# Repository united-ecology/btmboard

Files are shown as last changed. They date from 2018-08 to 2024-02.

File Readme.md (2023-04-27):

# BtM Board 1.2

This project is an Arduino based datalogger for monitoring moss conductance as well as environmental humidity and temperature. Up to eight moss and/or lichen samples can be logged in parallel using a single BtMboard. If you are interested in using it, do not hesitate to contact :)

This repository is associated with the following publication: Leo, M., Lareo, A., Garcia-Saura, C., Hortal, J., Medina, N. G. BtM, a Low-cost Open-source Datalogger to Estimate the Water Content of Nonvascular Cryptogams. *J. Vis. Exp.* (145), e58700, [doi:10.3791/58700](https://doi.org/10.3791/58700) (2019).

A video with further instructions on how to build and use the datalogger can be found in the paper link: [BtM, a Low-cost Open-source Datalogger to Estimate the Water Content of Nonvascular Cryptogams](https://www.jove.com/video/58700/btm-low-cost-open-source-datalogger-to-estimate-water-content). Notice that version 1.0 was used in the recording, and it might slightly differ from the current version.

Do not switch off the datalogger while measuring (LED light on). It can be switched off safely during the sleeping period (LED light off). 

## Sofware

This software folder contains the source code needed to use the BtM datalogger. Make sure you choose the appropriate board (Pro Mini 328 3.3V) in the Arduino IDE.

*Libraries* contains the libraries needed for the datalogger. Copy them to your local Arduino IDE installation in the `/libraries` folder. 

*Clock* contains a project to set up the date / hour of the BtM datalogger. It will set it according to your local system clock.

*Datalog* contains the main project used to log the data. The sampling frequency can be controlled here by modifying `interval` (sleeping period in seconds). Make sure you select the appropriate sensor (SHT7x / SHT85). See [this documentation](datalog-config.md) on how to do it.

## Hardware
The hardware folder contains the KiCAD project files for the BtM PCB Board. See the **List of Components** section for details about the hardware needed to assembly the board.

### Assembly schematic

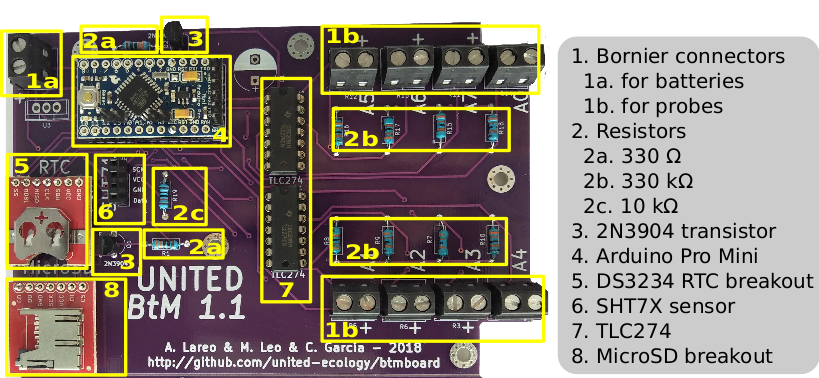
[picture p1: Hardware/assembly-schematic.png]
Assembly Schematic


### Obtaining measures

 As shown in the image, a voltage divider between each sample (Moss) and a resistor reference (Ref) with a known value (330KΩ in our case) is used to calculate the conductance measure. Probes are applied to each moss/lichen sample. Reference resistor value must be selected through calibration and based on previous measures of the cryptogams. It provides a resolution of one order of magnitude around the reference value (in our case, 100 – 1000 KΩ).

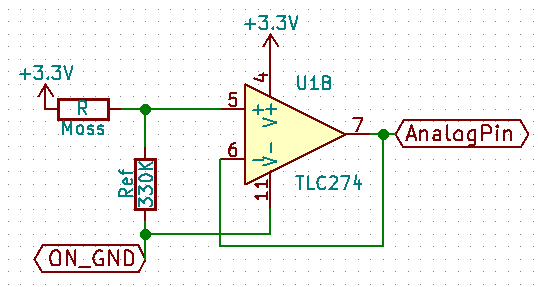
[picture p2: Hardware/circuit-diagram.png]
Circuit Diagram


### List of Components
* BtMboard circuit (PCB)
* Arduino Pro Mini 328 3.3 V
* FTDI Basic Breakout
* MiniUSB to USB cable adapter
* TLC274 operational amplifier
* 2.54 mm breakout pin strip
* Resistors (8 x 330 Kohm, 2 x 330 Ohm, 1 x 10 KOhm)
* 2N3904 Transistor
* 9 x Bornier connectors, 2x1 5.08 mm
* Batteries and battery holder with switch
* Sensirion SHT7x / SHT85
* DS3234 RTC Breakout (clock)
* CR1225 3V Coin-cell battery
* MicroSD Transflash breakout

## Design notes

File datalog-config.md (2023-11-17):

# Datalog

## Logging interval

Modify this portion of the code for modifying the logging interval (default to 10 seconds):
```
const uint8_t interval = 10;  // set logging interval in SECONDS, eg: set 300 seconds for an interval of 5 mins
```

For example, to log every 10 minutes:
```
const uint8_t interval = 600;  // set logging interval in SECONDS, eg: set 300 seconds for an interval of 5 mins
```

## Sensor selection

Modify this portion of the code for selecting the appropriate sensor (default to SHT85):
```
// SELECT the appropriate sensor
// #define SHT71SENSOR
#define SHT85SENSOR
```

If you are using **SHT7x**, change it this way:
```
// SELECT the appropriate sensor
#define SHT71SENSOR
// #define SHT85SENSOR
```
## Problem with time shifts

Depending in the system configuration, you may experience problems with time shifts when programming the Arduino board. To fix this:

1. Find the following line in the code:
```
const int timeshift = 0; // Change this variable if you are experiencing time shift problems (in seconds, i.e. -3600 to shift one hour) 
```

2. Modify it to increase/decrease the shift, in order to adjust the clock time to the correct time.

## Serial debug RTC

Uncomment this (remove //) to turn on clock debug prompts through the serial port:
```
#define DEBUG_RTC
```

## Serial debug sensors

Uncomment this (remove //) to turn on sensor debug prompts through serial port:
```
#define DEBUG_SENSORS
```

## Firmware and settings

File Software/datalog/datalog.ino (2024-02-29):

//****************************************************************
// Data logging software from Leo, Lareo et al. 2018
// v1.2 <angel.lareo@gma>
//****************************************************************

// SELECT the appropriate sensor
// #define SHT71SENSOR
#define SHT85SENSOR

#include <EEPROM.h>
#include <RtcDS3234.h>
#ifdef SHT71SENSOR
  #include <Sensirion.h>
#else // SHT85SENSOR
  #include <SoftwareWire.h>
  #include <SHT85.h>
#endif
#include <SdFat.h>
#include <sdios.h>
#include <SPI.h>
#include <PowerSaver.h>

// #define DEBUG_RTC
// #define DEBUG_SENSORS
#define DEBUG_SD 0
#define PRINT_DELAY 7 // Increase this if strange characters appear in serial prints

// Constants
#define POWA 4    // pin 4 supplies power to microSD card breakout and SHT15 sensor
#define PINON 7
#define NREADS 4
#define ANALOGMAX 8
#define RtcSquareWavePin 8 // Arduino Pro Mini
#define maxSDLines2Serial 5
#define line_buffer_size 300
#define SHT85_ADDRESS 0x44

// Launch Variables   ******************************
const uint16_t interval = 300;  // set logging interval in SECONDS, eg: set 300 seconds for an interval of 5 mins
char filename_prefix[] = "";
char filename_ext[] = ".csv";
char filename[20];    // Set filename Format: "12345678.123". Cannot be more than 8 characters in length, contain spaces or begin with a number
const int timeshift = 0; // Change this variable if you are experiencing time shift problems (in seconds, i.e. -3600 to shift one hour) 

// Global objects and variables   ******************************
const int SDcsPin = 9;        // pin 9 is CS pin for MicroSD breakout
const uint8_t DS3234_CS_PIN = 10; // RTC SS pin
const uint8_t SHT_clockPin = 3;   // pin used for SCK on SHT85 breakout
const uint8_t SHT_dataPin = 5;    // pin used for DATA on SHT85 breakout
const float VCC = 3.3;            // Con Vcc=3.3V lo máximo que da el TL274 es 2.73V
const float Voffset = 0.00;
int RValue = 330;
int fileLastHour=-1;
int nSDLines2Serial=0;

RtcDateTime time;
PowerSaver chip;  	// declare object for PowerSaver class
RtcDS3234<SPIClass> RTC(SPI, DS3234_CS_PIN);

#ifdef SHT71SENSOR
  Sensirion sensor(SHT_dataPin, SHT_clockPin);  // declare object for SHT71 class
#else // SHT85SENSOR
  SoftwareWire myWire(SHT_dataPin, SHT_clockPin);
  SHT85 sensor;  // declare object for SHT85 class
#endif
SdFat sd; 		    // declare object for SdFat class

// ISR ****************************************************************
ISR(PCINT0_vect)  // Interrupt Vector Routine to be executed when pin 8 receives an interrupt.
{
  asm("nop");
}

// setup ****************************************************************
void setup()
{
  Serial.begin(115200); // open serial at 19200 bps
  while (!Serial);
  
  pinMode(POWA, OUTPUT);      // set output pins
  pinMode(PINON, OUTPUT);     // set output pins
  digitalWrite(POWA, LOW);    // turn off SD card
  digitalWrite(PINON, LOW);   // turn off sensors

  // set the interupt pin to input mode
  pinMode(RtcSquareWavePin, INPUT_PULLUP); // external pullup maybe required still
  
  SPI.begin();

  setupRTC();

  time = RTC.GetDateTime();

  #ifdef SHT85SENSOR
    myWire.begin();
    sensor.begin(SHT85_ADDRESS,&myWire);
    myWire.setClock(100000UL);
  #endif
  
  delay(1);

  chip.sleepInterruptSetup();
}

// loop ****************************************************************
void loop()
{ 
  #ifdef DEBUG_RTC
    Serial.print(time.Hour());
    Serial.print(":");
    Serial.print(time.Minute());
    Serial.print(":");
    Serial.print(time.Second());
  #endif

  time = time+interval;
  #ifdef DEBUG_RTC
    Serial.print(" - Next alarm at ");
    SerialDebugRTC();
    delay(PRINT_DELAY);
  #endif
  setNextAlarm(time);      //set next alarm before sleeping
  
  chip.turnOffADC();        // turn off ADC to save power
  chip.turnOffSPI();        // turn off SPI bus to save power
  //chip.turnOffWDT();      // turn off WatchDog Timer to save power (does not work for Pro Mini - only works for Uno)
  chip.turnOffBOD();        // turn off Brown-out detection to save power
  pinMode(SCK,OUTPUT);      // turnOffSPI lo había dejado en alto y como entrada
  digitalWrite(SCK, LOW);   // Para garantizar que el LED verde de SCK se apaga

  chip.goodNight();    // put processor in extreme power down mode - GOODNIGHT!
  // this function saves previous states of analog pins and sets them to LOW INPUTS
  // average current draw on Mini Pro should now be around 0.195 mA (with both onboard LEDs taken out)
  // Processor will only wake up with an interrupt generated from the RTC, which occurs every logging interval

  // code will resume from here once the processor wakes up =============== //
  chip.turnOnADC();    // enable ADC after processor wakes up
  chip.turnOnSPI();   // turn on SPI bus once the processor wakes up
  delay(1);    // important delay to ensure SPI bus is properly activated

  time = RTC.GetDateTime();
  uint8_t hour = time.Hour();

  #ifdef DEBUG_RTC
    Serial.print("Awake at ");
    SerialDebugRTC();
  #endif
  
  RTC.LatchAlarmsTriggeredFlags();    // clear alarm flag
  
  pinMode(POWA, OUTPUT);
  pinMode(PINON, OUTPUT);

  float temperature;
  float humidity; 
  float RData[8];

  // Medida analógica de impedancias
  digitalWrite(PINON, HIGH);    // turn on sensors
  delay(10);
  getDataFromSensors(&temperature,&humidity,RData);
  #ifdef DEBUG_SENSORS
    SerialDebugSensors(&temperature,&humidity,RData);
  #endif
  digitalWrite(PINON, LOW);     // turn off microSD card to save power

  // Grabación de medidas en memoria SD
  digitalWrite(POWA, HIGH);    // turn on SD card
  delay(1);    // give some delay to ensure RTC and SD are initialized properly
  
  pinMode(SDcsPin, OUTPUT);
  if (!sd.begin(SdSpiConfig(SDcsPin))){   // very important - reinitialize SD card on the SPI bus
    if (DEBUG_SD) Serial.println("SD ERROR");
    sd.initErrorPrint();
    return;
  }


  if (hour==0 && fileLastHour==23){
    fileLastHour=-1;
  }
  if (hour>fileLastHour){
    delay(1);
    fileLastHour = time.Hour();
    doFilename(time.Month(),time.Day(),fileLastHour);
    initFile();
    delay(1);
  }
  
  printDataEntry2File(&temperature,&humidity,RData);
  lastSDLine2Serial();
  // if (nSDLines2Serial<maxSDLines2Serial){
  //   nSDLines2Serial++;
  //   Serial.println("");
  //   Serial.print("[");
  //   Serial.print(nSDLines2Serial);
  //   Serial.print("] ");
  //   lastSDLine2Serial();
  // }
  
  sd.end();
  delay(1);
//  SPCR = 0;  // reset SPI control register
  digitalWrite(POWA, LOW);    // turn off microSD card to save power
  digitalWrite(PINON, LOW);   // turn off microSD card to save power
}






// ------------------------------------------------
//  FUNCTIONS
// ------------------------------------------------

void setupRTC(){
  RTC.Begin();

  RtcDateTime compiled = RtcDateTime(__DATE__, __TIME__);

  compiled += timeshift;
  if (timeshift != 0) {
     RTC.SetDateTime(compiled);
  }
  
  if (!RTC.IsDateTimeValid()) {
      // Serial.println("RTC lost confidence in the DateTime!");
      RTC.SetDateTime(compiled);
  }

  if (!RTC.GetIsRunning()) {
      // Serial.println("RTC was not actively running, starting now");
      RTC.SetIsRunning(true);
  }
  
  RtcDateTime now = RTC.GetDateTime();
  if (now < compiled) {
      // Serial.println("RTC is older than compile time!  (Updating DateTime)");
      RTC.SetDateTime(compiled);
  }
  
  RTC.Enable32kHzPin(false);
  RTC.SetSquareWavePin(DS3234SquareWavePin_ModeAlarmBoth); 
}

void initFile(){
  ofstream file(filename,ios_base::app);
  if (!file.is_open()) {
    if (DEBUG_SD){
      Serial.print("SDFile ERR: ");
      Serial.println(filename);
    }
    sd.errorHalt("open");
  }
  file << "Date/Time,Temp(C),RH(%),A0_Imp(ohm),A1_Imp(ohm),A2_Imp(ohm),A3_Imp(ohm),A4_Imp(ohm),A5_Imp(ohm),A6_Imp(ohm),A7_Imp(ohm)\n";    // Print header to file
  file.close();    // close file - very important
}

void getDataFromSensors(float* temperature, float* humidity, float* RData){
  for (int a = A0; a < A0 + ANALOGMAX; a++)
    for (int i = 0; i < NREADS; i++)
      analogRead(a);  // first few readings from ADC may not be accurate, so they're cleared out here
  delay(1);

  // Read moss data
  for (int a = 0; a < ANALOGMAX; a++){
    float adcData = averageADC(A0+a);
    RData[a] = mossImpedance(adcData, RValue); //Reference resistor value
  }

  #ifdef SHT71SENSOR
    float dew;
    sensor.measure(temperature,humidity,&dew);
  #else // SHT85SENSOR
    // Read sensor data
    sensor.read(); 
    *temperature = sensor.getTemperature();
    *humidity = sensor.getHumidity();
  #endif
}

void setNextAlarm(RtcDateTime next){
  DS3234AlarmOne alarm1(
            next.Day(),
            next.Hour(),
            next.Minute(), 
            next.Second(),
            DS3234AlarmOneControl_HoursMinutesSecondsMatch);
  RTC.SetAlarmOne(alarm1);
  RTC.LatchAlarmsTriggeredFlags();
}

void lastSDLine2Serial(){
  Serial.print("buff: ");
  char buffer[line_buffer_size];

  fstream file(filename);
  
  bool keepLooping = true;
  file.seekg(-3,ios_base::end);

  while(keepLooping) {
    char ch;
    file.get(ch);                            // Get current byte's data
    
    if((int)file.tellg() <= 1) {             // If the data was at or before the 0th byte
        file.seekg(0);                       // The first line is the last line
        keepLooping = false;                // So stop there
    }
    else if(ch == '\n') {                   // If the data was a newline
        keepLooping = false;                // Stop at the current position.
    }
    else {                                  // If the data was neither a newline nor at the 0 byte
        file.seekg(-2,ios_base::cur);        // Move to the front of that data, then to the front of the data before it
    }
  }
           
  file.getline(buffer, line_buffer_size, '\n');                      // Read the current line
  file.close();
  
  Serial.println(buffer);     // Display it
  delay(PRINT_DELAY);

}

void printDataEntry2File(float* temperature, float* humidity, float* RData){
  ofstream file(filename,ios_base::app);

  file << time.Year();
  file << "-";
  int d = time.Month();
  if (d < 10) file << '0';
  file << d;
  file << "-";
  d = time.Day();
  if (d < 10) file << '0';
  file << d;
  file << " ";
  d = time.Hour();
  if (d < 10) file << '0';
  file << d;
  file << ":";
  d = time.Minute();
  if (d < 10) file << '0';
  file << d;
  file << ":";
  d = time.Second();
  if (d < 10) file << '0';
  file << d;
  file << ",";
  if (*temperature < 10) file << '0';
  file << *temperature;
  file << ",";
  if (*humidity < 10) file << '0';
  file << *humidity;
  for (int a = 0; a < ANALOGMAX; a++){
    file << ",";
    file << RData[a];
  }
  file << "\n";
  file.close();
  
  //Needed who knows why ¯\_(ツ)_/¯
  file.open(filename,ios_base::app);
  file.close();
}

// Averaging ADC values to counter noise in readings  *********************************************
float averageADC(int pin){
  float sum = 0.0;
  for (int i = 0; i < NREADS; i++){
    sum = sum + analogRead(pin);
  }
  float average = sum / NREADS;
  return average;
}

// Get mossImp ****************************************************************
float mossImpedance(float adc, int R){
  float Zmoss=99999.0;
  float V = (adc * VCC) / 1023.0;
  //return (VCC * R) / V - R;
  V = V - Voffset;
  if (V>0.0109) Zmoss = ((VCC * R) / V) - R;
  return (Zmoss);
}

void doFilename(int month, int day, int hour){  
  char c[3];
  int d;
  strcpy(filename, filename_prefix);
  
  if (month >= 10){
    c[1]= month%10 + '0';
    month/=10;
    c[0]=month+'0';
    c[2]='\0';
    strcat(filename, c);
  }
  else{
    c[0]=month+'0';
    c[1]='\0';
    strcat(filename, c);
  }
  
  c[0]='_'; c[1]='\0';
  strcat(filename, c);
  
  if (day >= 10){
    c[1] = day%10 + '0';
    day/=10;
    c[0]=day+'0';
    c[2]='\0';
    strcat(filename, c);
  }
  else{
    c[0]=day+'0';
    c[1]='\0';
    strcat(filename, c);
  }
  
  c[0]='_'; c[1]='\0';
  strcat(filename, c);
  
  if (hour >= 10){
    c[1] = hour%10 + '0';
    hour/=10;
    c[0]=hour+'0';
    c[2]='\0';
    strcat(filename, c);
  }
  else{
    c[0]=hour+'0';
    c[1]='\0';
    strcat(filename, c);
  }
  
  strcat(filename, filename_ext);
  
  if (DEBUG_SD){
    Serial.print("filename: ");
    Serial.println(filename);
    delay(1);
  }
}

// SERIAL DEBUG
#ifdef DEBUG_RTC
void SerialDebugRTC(){
  Serial.print(time.Year());
  Serial.print("-");
  Serial.print(time.Month());
  Serial.print("-");
  Serial.print(time.Day());
  Serial.print(" ");
  
  Serial.print(time.Hour());
  Serial.print(":");
  Serial.print(time.Minute());
  Serial.print(":");
  Serial.println(time.Second()); 
}
#endif 

#ifdef DEBUG_SENSORS
void SerialDebugSensors(float* temperature, float* humidity, float* RData){
  Serial.print("Status: ");
  Serial.println();
  Serial.print(*temperature);
  Serial.print(" ");
  Serial.print(*humidity);
  for (int a = 0; a < ANALOGMAX; a++){
    Serial.print(" ");
    Serial.print(RData[a]);
  }
  Serial.println(" ");
}
#endif

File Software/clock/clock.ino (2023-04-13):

// RTC.configure(MOSI, MISO, CLK, CS)
// RTC.setDateTime(day, month, year, hour, minute, second)
 
#include <RtcDS3234.h>
#include <SPI.h>

const uint8_t DS3234_CS_PIN = 10; // RTC SS pin

RtcDS3234<SPIClass> RTC(SPI, DS3234_CS_PIN);

void setup()
{
  Serial.begin(115200);

  // Following line sets the RTC to the date & time this sketch was compiled:
  setupRTC(); 
}
 
void loop()
{
  RtcDateTime time = RTC.GetDateTime();

  int year,month,day,hour,minute,second;
  year=time.Year(); month=time.Month(); day=time.Day(); hour=time.Hour(); minute=time.Minute(); second=time.Second();

  Serial.println();
  delay(1000);
}

void setupRTC(){
  RTC.Begin();

  RtcDateTime compiled = RtcDateTime(__DATE__, __TIME__);

  if (!RTC.IsDateTimeValid()) {
      // Serial.println("RTC lost confidence in the DateTime!");
      RTC.SetDateTime(compiled);
  }

  if (!RTC.GetIsRunning()) {
      // Serial.println("RTC was not actively running, starting now");
      RTC.SetIsRunning(true);
  }
  
  RtcDateTime now = RTC.GetDateTime();
  if (now < compiled) {
      // Serial.println("RTC is older than compile time!  (Updating DateTime)");
      RTC.SetDateTime(compiled);
  }
  
  RTC.Enable32kHzPin(false);
  RTC.SetSquareWavePin(DS3234SquareWavePin_ModeAlarmBoth); 
}

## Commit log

2018-08-29 Changes in Readme.m
    [BtMusgo.sch]
2018-12-13 Bug fixes
    [BtMusgo.kicad_pcb]
2023-04-13 Updates to v1.2
    [BtMusgo-2023-03-10-18-52-42.sch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]
2023-04-19 Solved PINON problem for fixing sensors data.
    [datalog.ino]
2023-04-27 Fixed constant name problem
    [datalog.ino]
2023-05-17 Back to PowerSaver
2023-05-17 Fixed printing problem
2023-05-20 weird fix to correctly print data buffer to SD file
    [datalog.ino]
2023-05-31 SD printing fix
2023-06-05 Fix for increased power consumption
    [datalog.ino]
